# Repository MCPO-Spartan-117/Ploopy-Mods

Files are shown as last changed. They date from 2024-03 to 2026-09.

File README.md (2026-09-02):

# Ploopy Mods

This repo is a collection of [Ploopy Mouse](https://github.com/ploopyco) Kicad Conversions, PCB Replacements and mods.  
You can visit their [store page here](https://ploopy.co) and the [firmware here](https://github.com/qmk/qmk_firmware) or their [website here](https://qmk.fm).

## Test state
Nothing has been tested, make any of this at your own risk.

## Currently has mods for:

* K = Kicad Conversions
* P = PCB Replacements
* M = Mods
* P+M = PCB Replacement only Mods
* P=M = PCB Replacement that require Mods

[Ploopy Thumb Trackball](https://github.com/ploopyco/thumb-trackball): P P=M

## Directories:

* Models: A directory for 3D models made from or for either Kicad or Freecad
* PCBs: Where kicad PCBs are stored
* Printables: Models you are meant to print
* Project-files: Global directory for Kicad symbols and footprints

## TODO:

* Rotary Encoder version + Lighter scroll wheel
* Rework optical sensor version
* (Full?) hall effect sensor version
* D2FC switches version?
* Ribbion cable/cabled version?
* Seperated/PCBless design
* Remake BTUs
* 3-4mm BTUs?
* PTFE BTUs?
* Port to other Ploopies
* Port to other PCB Manufacturers
* (Handsolderable?) LEDs?
* Port originals to kicad?
* Convert originals to ARM?

## Contributions

You want to help checking off the todo list, make mods of your own and submit them or think you can make a existing mod better?  
You can make a [pull request](https://docs.github.com/en/pull-requests/collaborating-with-pull-requests/proposing-changes-to-your-work-with-pull-requests/creating-a-pull-request) detailing what you are doing and we'll look over it.

However please use [Kicad for PCBs](https://www.kicad.org) or [Freecad for Models](https://www.freecad.org) and use their native formats, they are open source, free and easily obtainable, using other CADs and/or formats will make it harder to work with and we may outright reject them because of this.

This resource is good for [learning markdown](https://www.markdownguide.org/basic-syntax) for any READMEs.

## Kicad Instructions

1. Use the [Archive 3D Models Plugin](https://github.com/MitjaNemec/Archive3DModels) for Kicad with the default path.
2. Make relative symlinks named Project-files and packages3D to Project-files and Models/Kicad respectively in your PCB project directory, it will keep all the symbols, footprint and 3D models in one place to make it easily transportable, example in PCBs/JLCPCB/Thumb-v1.

## Freecad Instructions

1. Nothing atm.

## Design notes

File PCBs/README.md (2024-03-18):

Put your PCB directory under a subdirectory named after the PCB Manufacturer here or in the Prototype directory if you haven't made it for any specific manufacturer.  
(no guarantee they'll be accepted by the manufactor you choose if they don't conform to their specs).

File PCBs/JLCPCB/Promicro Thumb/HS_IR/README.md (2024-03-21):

# Promicro Thumb-HS_IR
## WARNING, THIS BOARD IS MEANT FOR A 3.3V BOARD, THE SENSOR WON'T WORK AS IT ONLY HAS A REGULATOR FOR 3.3V to 1.8V FOR THE LED, NOT THE SENSOR'S 3.3V!!!

This PCB is designed to offload all the processing to a 3.3V Promicro sized/pinout board, so we can work with a 2 layer board and we can replace the processing board with a better/more functioning one if we want to.  
We intentionally didn't use the USB VBUS directly for components as we wanted to be able to support wireless [ZMK](https://zmk.dev) boards when it gets support for mouse APIs and we have a place where you can install a battery and switch.

These boards don't use a ESD component as it's on the MCU board.

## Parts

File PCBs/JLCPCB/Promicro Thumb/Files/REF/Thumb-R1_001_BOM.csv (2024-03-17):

Comment | Description | Designator | Quantity | Man. Part Number
D2LS-21 | Compact Surface-mounting Switch for long durability | BTN.SW.3, BTN.SW.4, BTN.SW.6, BTN.SW.8, LBS.SW.1, LBS.SW.2 | 6
0805 | 0805, X5R or better, Chip resistor, 1/8W 100PPM, Chip resistor | LED.C.20, LED.C.23, LED.R.9, LED.R.16, MCU.C.1, MCU.C.4, MCU.C.5, MCU.C.6, MCU.C.7, MCU.C.8, MCU.C.9, MCU.C.22, MCU.R.1, MCU.R.8, MOS.C.10, MOS.C.11, MOS.R.3, MOS.R.4, MOS.R.5, REG.C.12, REG.C.13, REG.C.14, REG.C.15, REG.C.16, REG.C.17, REG.C.18, SCW.R.1, SCW.R.2, SCW.R.3, SCW.R.4, USB.R.6, USB.R.7, USB.R.12, USB.R.13, USB.R.14, USB.R.15 | 36
IN-PI55TATPRPGPB | ADDRESS LED DISCRETE SERIAL RGB | LED.D.1, LED.D.3 | 2
IPC-7351 Fiducial 1mm | IPC-7351 Fiducial 1mm | MCH.FID.1, MCH.FID.2 | 2
Atmel_ICSP | 6-pin 0.100" ICSP header | MCU.J.1 | 1
HEADER2 | 2-pin 0.100" header | MCU.J.2 | 1
ATMEGA32U4RC-AU | IC MCU 8BIT 32KB FLASH 44TQFP | MCU.U.1 | 1
LFXTAL055663BULK | 8MHz ±20ppm Crystal 18pF 150 Ohms 4-SMD, No Lead | MCU.Y.1 | 1
PMW3360DM-T2QU | Optical Gaming Navigation Sensor | MOS.U.2 | 1
AP2202K-3.3 | 3.3V 150mA LDO regulator | REG.U.3 | 1
AP2204K-1.8 | Linear Voltage Regulator IC 1 Output 150mA SOT-23-5 | REG.U.4 | 1
IR12-21C/TR8 or VSMB10940 | Infrared (IR) Emitter 880nm 1.3V 50mA 1mW/sr @ 20mA 30° 2-SMD, No Lead | SCW.D.11, SCW.D.12 | 2
PT26-51B/TR8 or PT12-21B/TR8 | Phototransistor 940nm Side View 1206 (3216 Metric) | SCW.Qt.1, SCW.Qt.2 | 2
ACML-0805-601-T | FERRITE BEAD 600 OHM 0805 1LN | USB.FB.1, USB.FB.2, USB.FB.3 | 3
DX07S016JA1R1500 | USB-C (USB TYPE-C) USB 2.0 Receptacle Connector 24 (16+8 Dummy) Position Surface Mount, Right Angle; Through Hole | USB.J.3 | 1
IP4220CZ6,125 | TVS DIODE 5.5V 6TSOP (Low capacitance, USB) | USB.Z.1 | 1

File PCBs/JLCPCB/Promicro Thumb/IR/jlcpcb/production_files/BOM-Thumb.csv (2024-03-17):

Comment | Designator | Footprint | LCSC
600 | FB1,FB2,FB3 | R_0805_2012Metric | C1017
2u2 | C1,C2,C3,C4 | C_0805_2012Metric | C15850
100R | R5,R7 | R_0805_2012Metric | C17408
10k | R3 | R_0805_2012Metric | C17414
1k | R6,R8 | R_0805_2012Metric | C17513
39R | R4 | R_0805_2012Metric | C17634
5k1 | R1,R2 | R_0805_2012Metric | C27834
XC6206P182MR | U2 | SOT-23-3 | C2909966
USB_C_Receptacle_USB2.0 | J1 | USB_C_Receptacle_G-Switch_GT-USB-7010ASV | C2988369
IR12-21C/TR8 | D1,D2 | IR12-21C_TR8 | C53672
PT26-51B/TR8 | Q1,Q2 | PT26-51B_TR8 | C55976

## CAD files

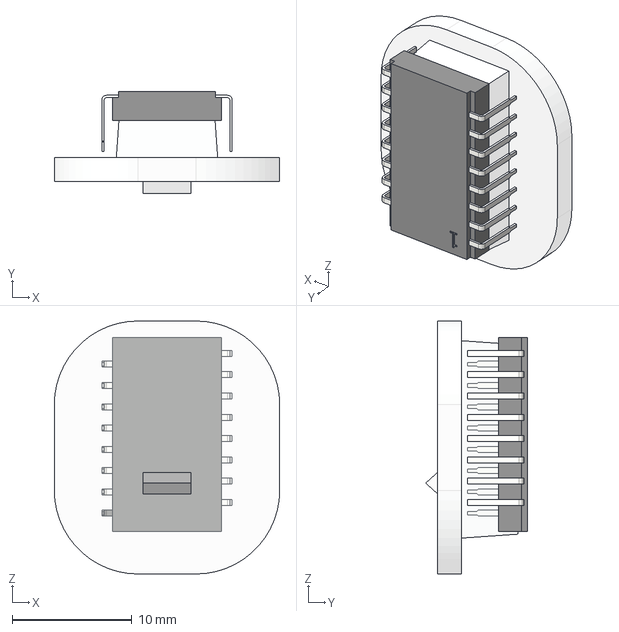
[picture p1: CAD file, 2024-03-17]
Models/Kicad/PMW3360-LM19-LSI-Assembly.stp
18.8 x 8.50 x 21.1 mm
LM19-LSI
PMW3360DM-T2QU

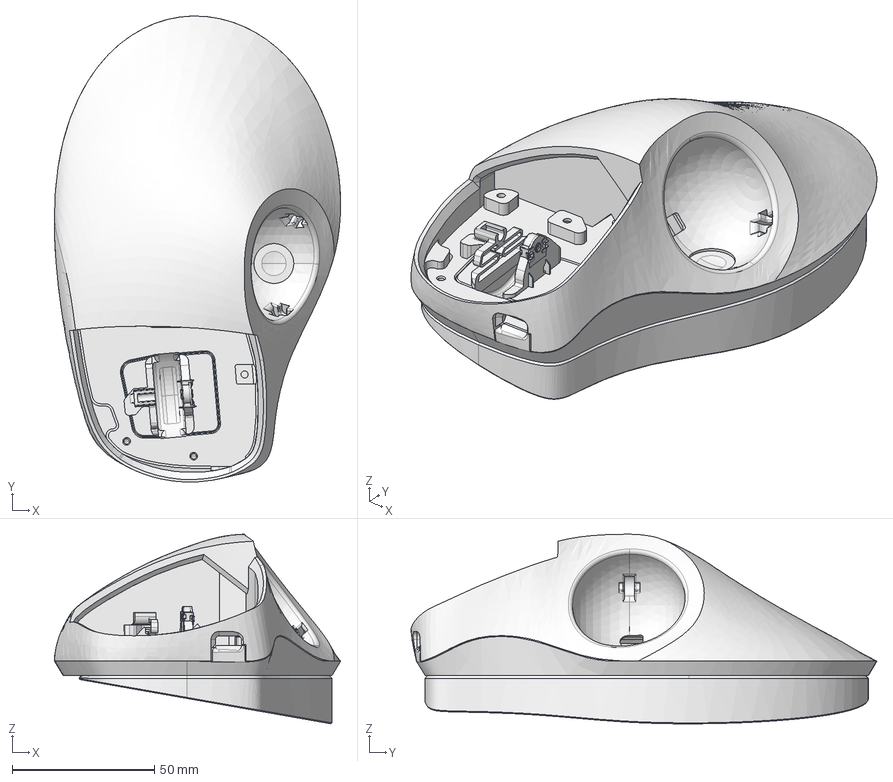
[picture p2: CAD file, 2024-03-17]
Models/Freecad/sensor.FCStd
100.7 x 164.0 x 66.8 mm
ThumbBodyParts-NoLogo-002
ThumbBodyParts-NoLogo-003
ThumbBodyParts-NoLogo-004
ThumbBodyParts-NoLogo-005
ThumbBodyParts-NoLogo-006

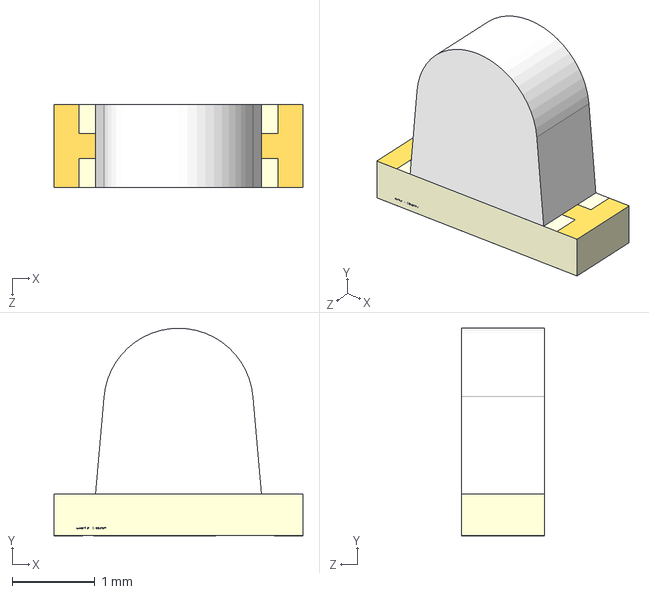
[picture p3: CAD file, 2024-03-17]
Models/Kicad/XZxx56x-1.step
3.00 x 2.50 x 1.00 mm

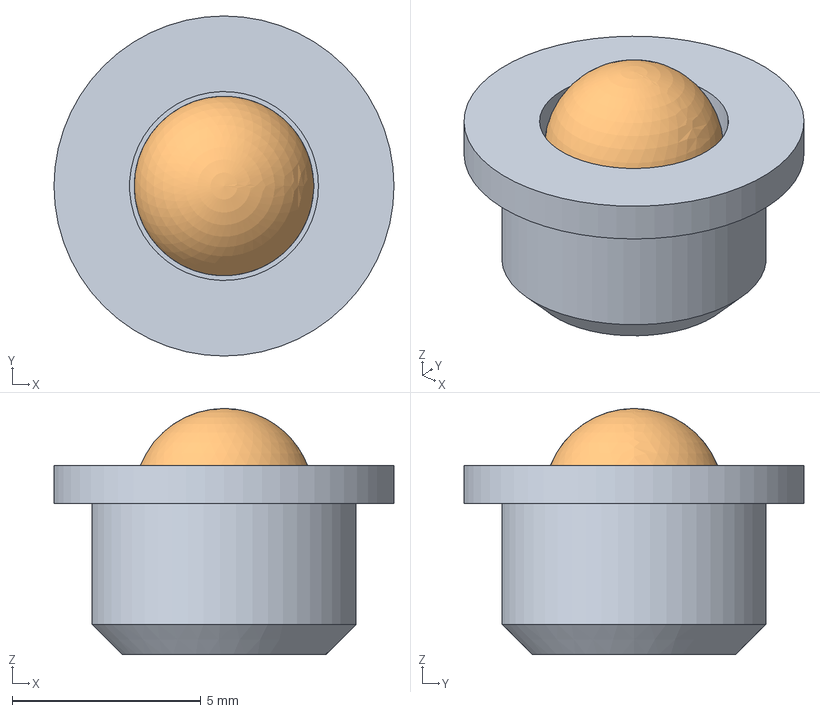
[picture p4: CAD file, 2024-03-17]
Printables/BTU-v1/BTU-7mm.FCStd
9.00 x 9.00 x 6.51 mm

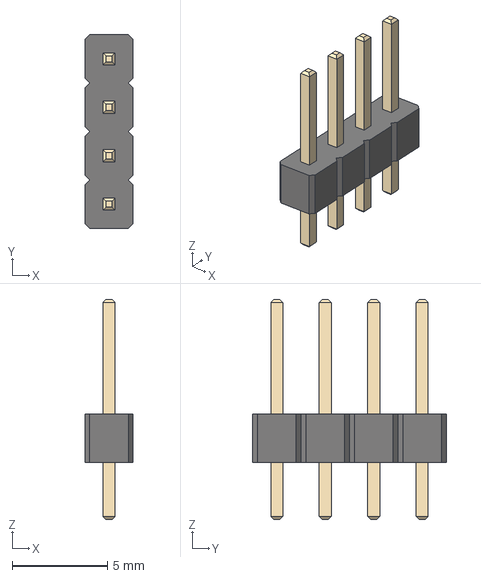
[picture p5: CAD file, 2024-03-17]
Models/Kicad/PinHeader_1x04_P2.54mm_Vertical.step
2.54 x 10.2 x 11.5 mm

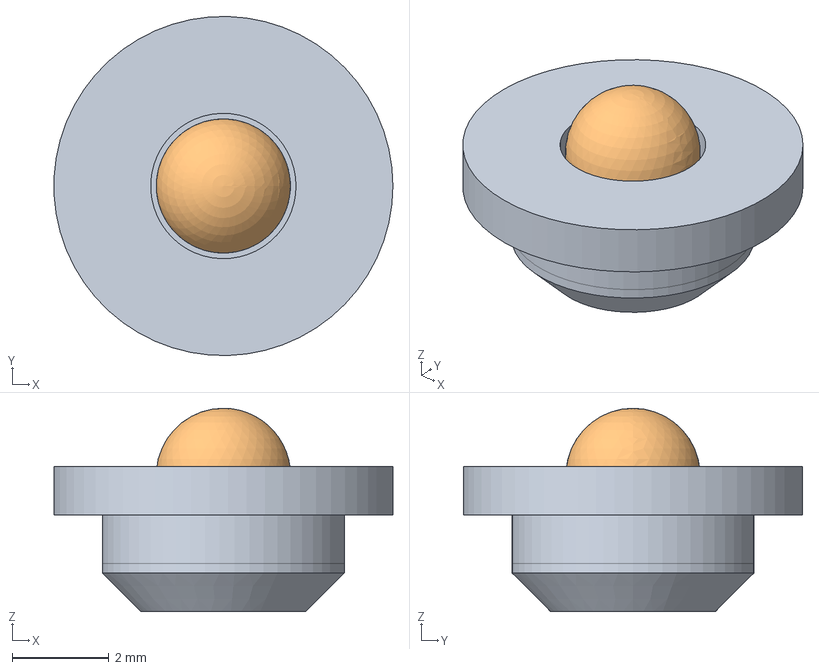
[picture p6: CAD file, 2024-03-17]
Printables/BTU-v1/BTU-5mm.FCStd
6.99 x 7.00 x 4.20 mm

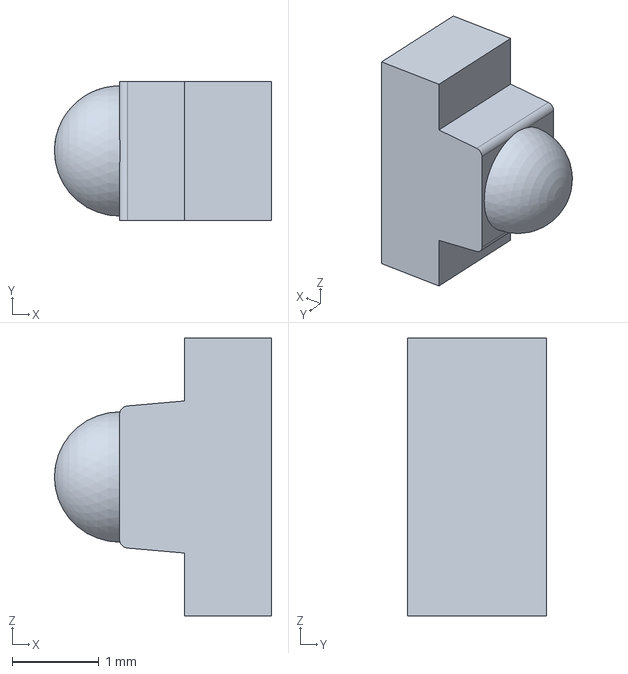
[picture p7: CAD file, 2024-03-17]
Models/Kicad/PT26-51B-TR8.stp
2.50 x 1.60 x 3.20 mm

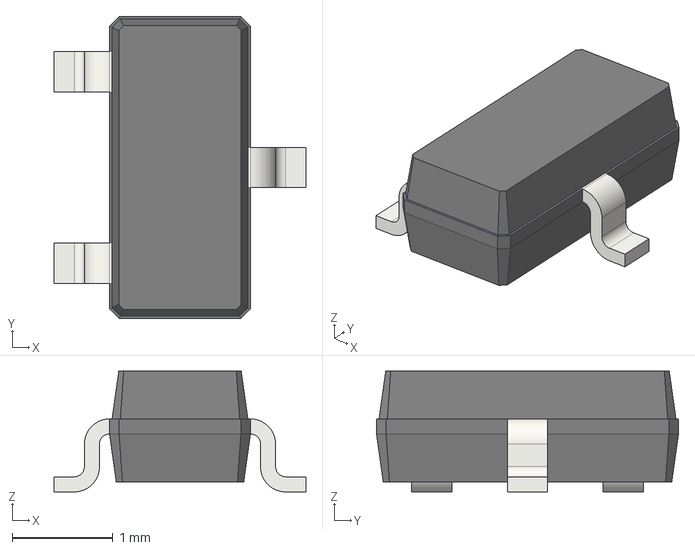
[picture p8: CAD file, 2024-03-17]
Models/Kicad/SOT-23.step
2.50 x 3.00 x 1.20 mm

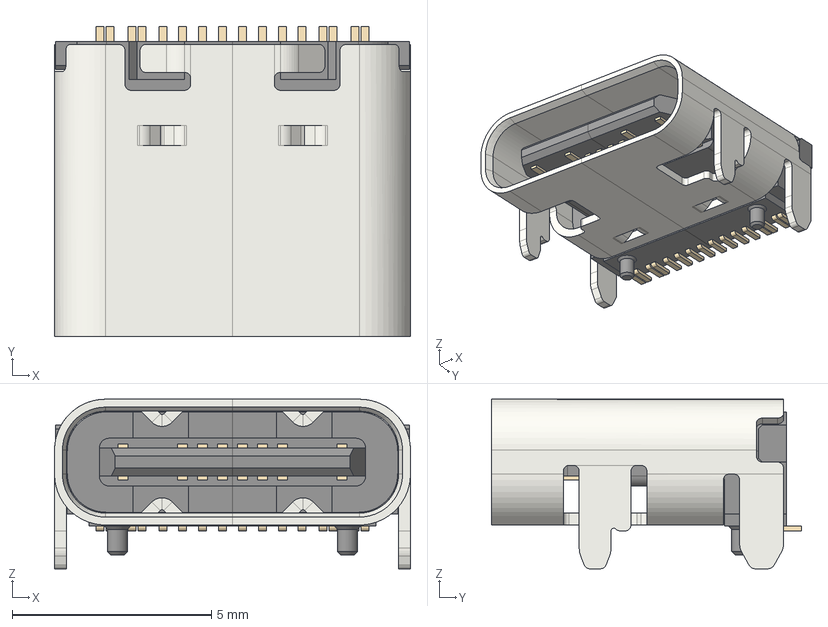
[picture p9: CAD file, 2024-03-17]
Models/Kicad/USB_C_Receptacle_GCT_USB4105-xx-A_16P_TopMnt_Horizontal.step
8.94 x 7.78 x 4.26 mm

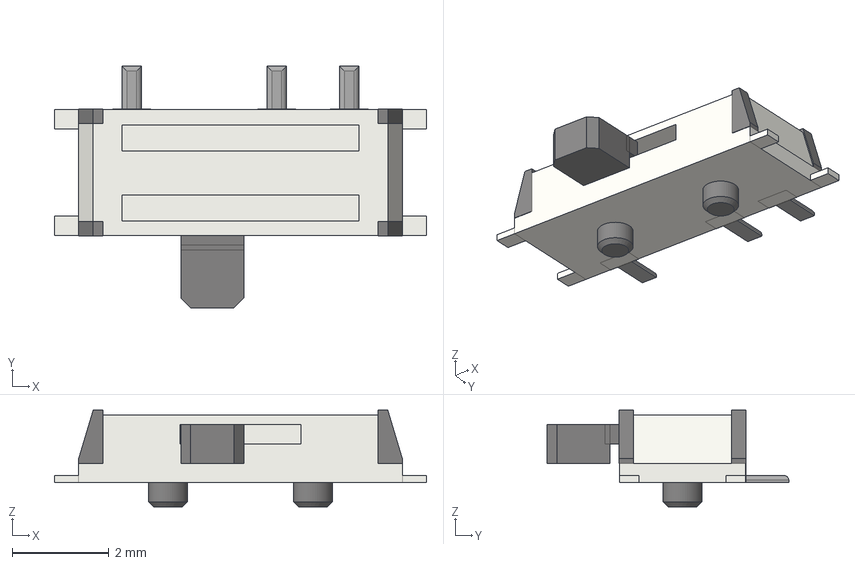
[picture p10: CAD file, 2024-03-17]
Models/Kicad/SW_SPDT_PCM12.step
7.70 x 5.00 x 2.00 mm

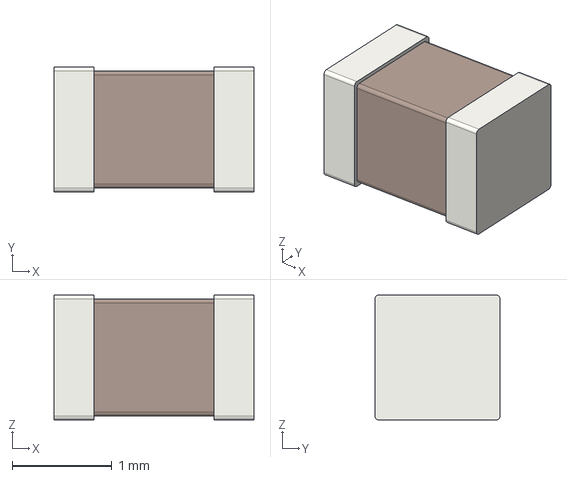
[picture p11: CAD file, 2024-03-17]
Models/Kicad/C_0805_2012Metric.step
2.00 x 1.25 x 1.25 mm

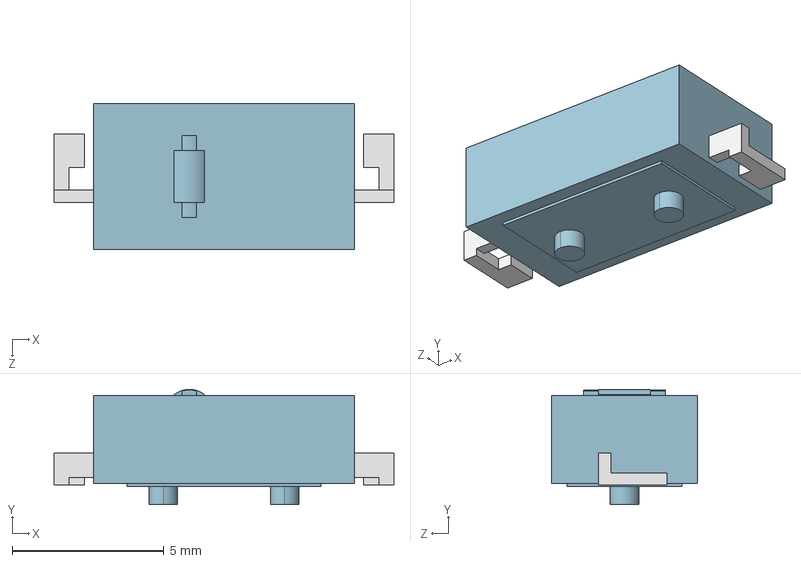
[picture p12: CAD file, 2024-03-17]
Models/Kicad/D2LS_21_20M.step
11.2 x 3.80 x 4.80 mm
D2LS_21_20M_BUTTON
D2LS_21_20M_BASE

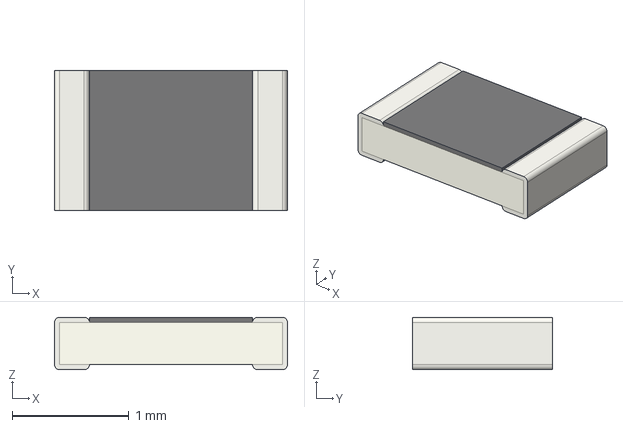
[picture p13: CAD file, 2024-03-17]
Models/Kicad/R_0805_2012Metric.step
2.00 x 1.20 x 0.45 mm

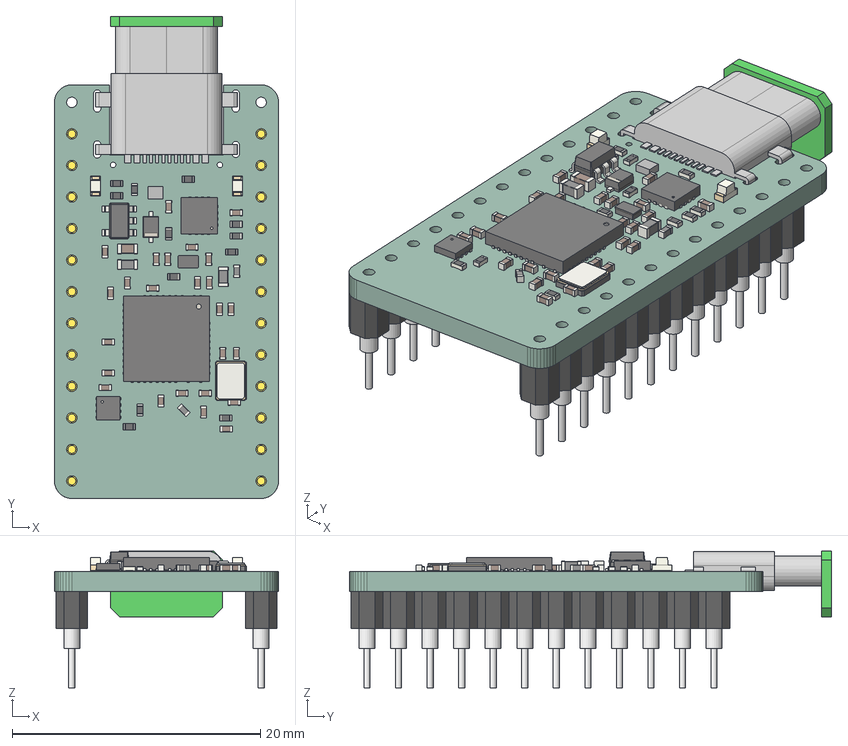
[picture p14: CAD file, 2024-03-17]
Models/Kicad/promicro.step
18.0 x 38.8 x 11.0 mm
mikoto PCB

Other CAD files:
Models/Kicad/PR(E,P)C003DAAN-RC.stp
Models/Kicad/m20-9990245_asm.stp

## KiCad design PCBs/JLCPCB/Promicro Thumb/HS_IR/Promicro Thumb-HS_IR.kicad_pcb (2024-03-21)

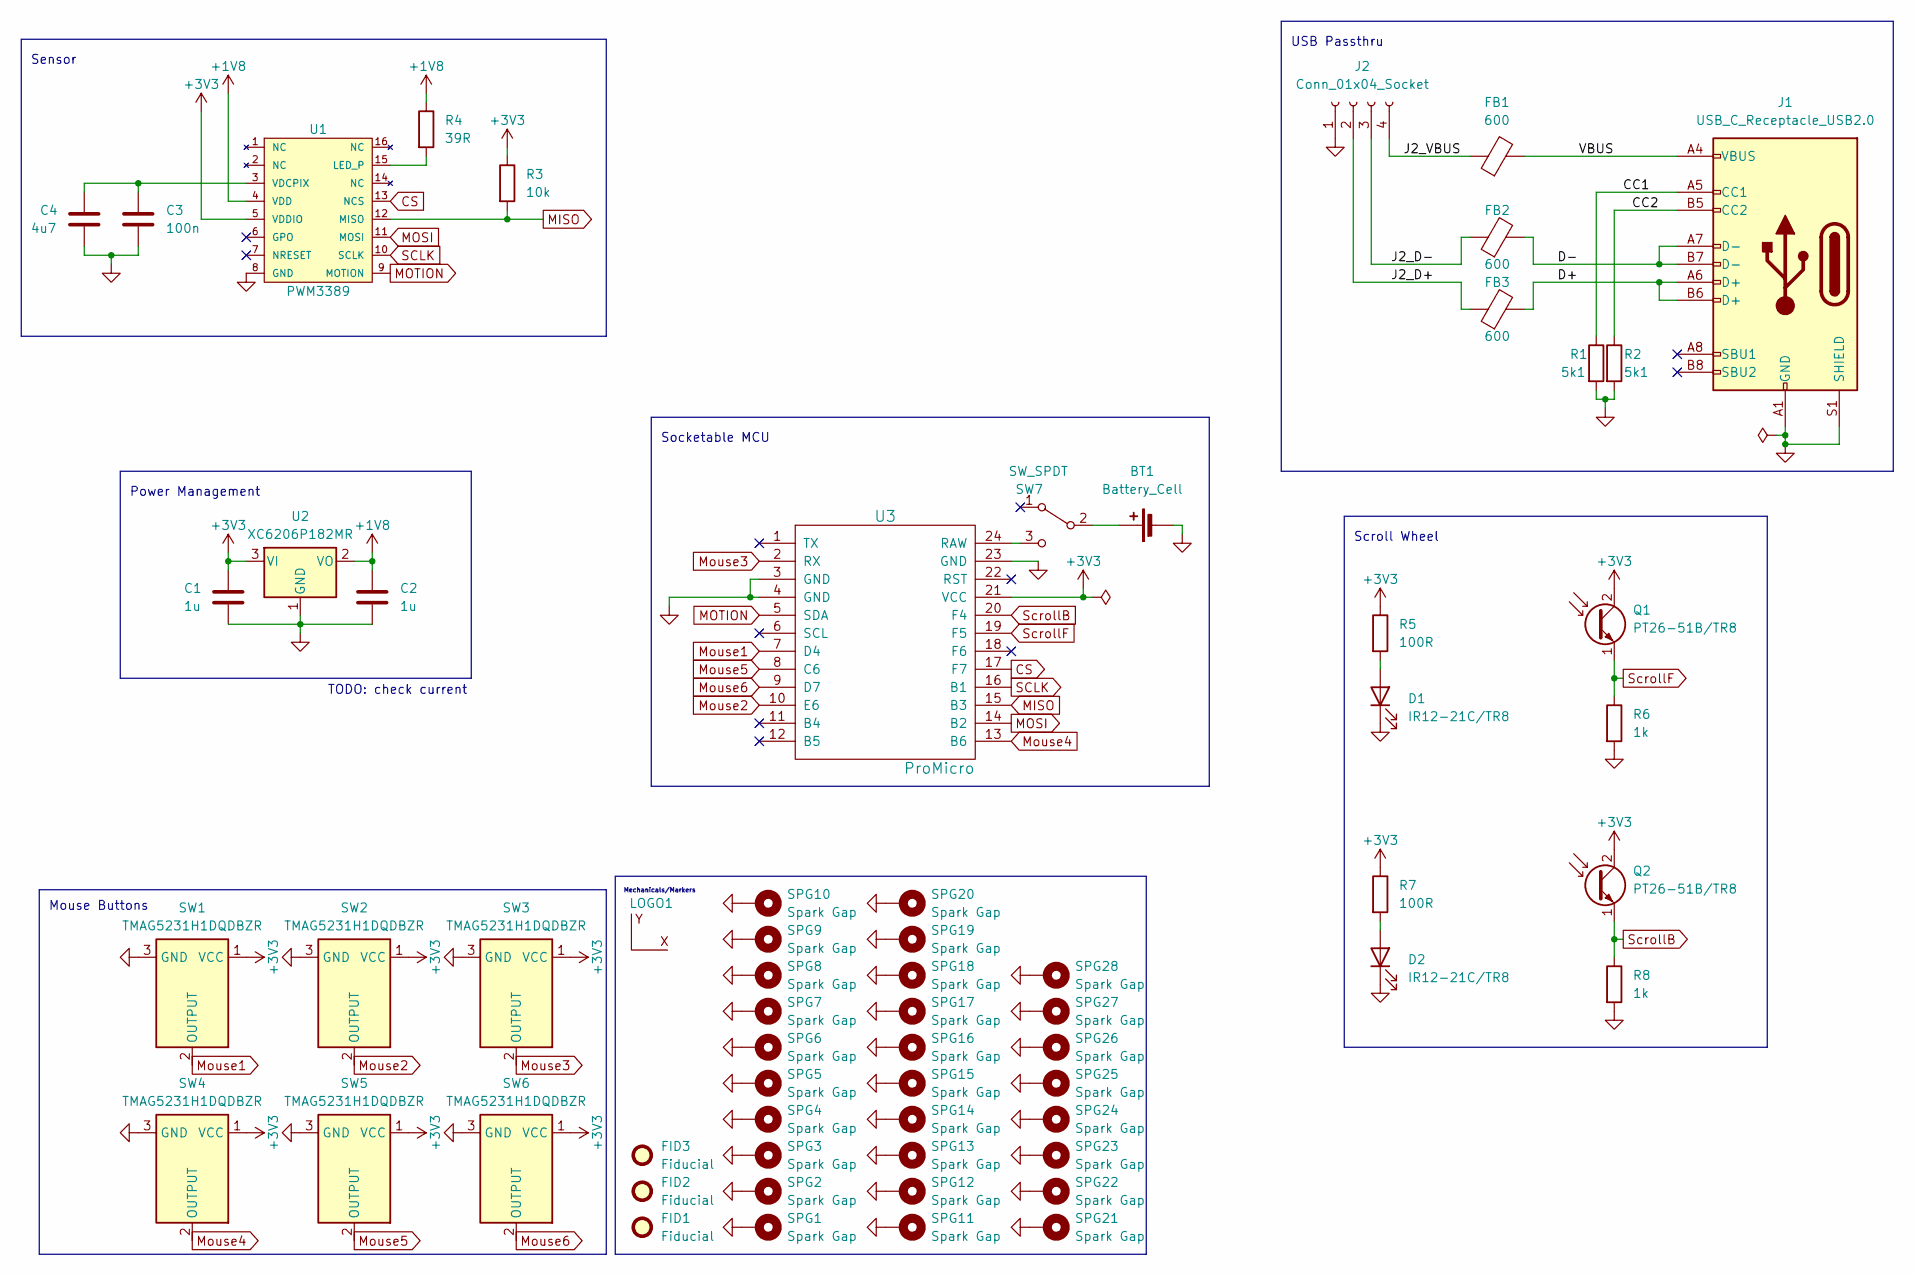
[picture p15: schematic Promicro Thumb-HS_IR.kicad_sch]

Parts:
BT1: Battery_Cell; Battery_pads_reversible
C1, C2: 1u; C_0805_2012Metric
C3: 100n; C_0805_2012Metric
C4: 4u7; C_0805_2012Metric
D1, D2: IR12-21C/TR8; IR12-21C_TR8
FB1, FB2, FB3: 600; R_0805_2012Metric
FID1, FID2, FID3: Fiducial; Fiducial_0.5mm_Mask1mm
J1: USB_C_Receptacle_USB2.0; USB_C_Receptacle_G-Switch_GT-USB-7010ASV
J2: Conn_01x04_Socket; PinHeader_1x04_P2.54mm_Vertical
LOGO1: Coordinate System-Ploopy
Q1, Q2: PT26-51B/TR8; PT26-51B_TR8
R1, R2: 5k1; R_0805_2012Metric
R3: 10k; R_0805_2012Metric
R4: 39R; R_0805_2012Metric
R5, R7: 100R; R_0805_2012Metric
R6, R8: 1k; R_0805_2012Metric
SPG1, SPG2, SPG3, SPG4, SPG5, SPG6, SPG7, SPG8, SPG9, SPG10, SPG11, SPG12, SPG13, SPG14, SPG15, SPG16, SPG17, SPG18, SPG19, SPG20, SPG21, SPG22, SPG23, SPG24, SPG25, SPG26, SPG27, SPG28: Spark Gap; SparkGap
SW1, SW2, SW3, SW4, SW5, SW6: TMAG5231H1DQDBZR; SOT-23
SW7: SW_SPDT; SW_SPDT_PCM12
U1: PWM3389; PMW3360DM-T2QU
U2: XC6206P182MR; SOT-23-3
U3: ProMicro

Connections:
+1V8: C2.1, R4.1, U1.4 (VDD), U2.2 (VO)
+3V3: C1.1, Q1.2 (C), Q2.2 (C), R3.1, R5.1, R7.1, SW1.1 (VCC), SW2.1 (VCC), SW3.1 (VCC), SW4.1 (VCC), SW5.1 (VCC), SW6.1 (VCC), U1.5 (VDDIO), U2.3 (VI), U3.21 (VCC)
/CC1: J1.A5 (CC1), R1.1
/CC2: J1.B5 (CC2), R2.1
/D+: FB3.2, J1.A6 (D+), J1.B6 (D+)
/D-: FB2.2, J1.A7 (D-), J1.B7 (D-)
/J2_D+: FB3.1, J2.2
/J2_D-: FB2.1, J2.3
/J2_VBUS: FB1.1, J2.4
/VBUS: FB1.2, J1.A4 (VBUS), J1.A9 (VBUS), J1.B4 (VBUS), J1.B9 (VBUS)
CS: U1.13 (NCS), U3.17 (F7)
GND: BT1.2 (-), C1.2, C2.2, C3.2, C4.2, D1.1 (K), D2.1 (K), J1.A1 (GND), J1.A12 (GND), J1.B1 (GND), J1.B12 (GND), J1.S1 (SHIELD), J2.1, R1.2, R2.2, R6.2, R8.2, SPG1.1, SPG2.1, SPG3.1, SPG4.1, SPG5.1, SPG6.1, SPG7.1, SPG8.1, SPG9.1, SPG10.1, SPG11.1, SPG12.1, SPG13.1, SPG14.1, SPG15.1, SPG16.1, SPG17.1, SPG18.1, SPG19.1, SPG20.1, SPG21.1, SPG22.1, SPG23.1, SPG24.1, SPG25.1, SPG26.1, SPG27.1, SPG28.1, SW1.3 (GND), SW2.3 (GND), SW3.3 (GND), SW4.3 (GND), SW5.3 (GND), SW6.3 (GND), U1.8 (GND), U2.1 (GND), U3.3 (GND), U3.4 (GND), U3.23 (GND)
MISO: R3.2, U1.12 (MISO), U3.15 (B3)
MOSI: U1.11 (MOSI), U3.14 (B2)
MOTION: U1.9 (MOTION), U3.5 (SDA)
Mouse1: SW1.2 (OUTPUT), U3.7 (D4)
Mouse2: SW2.2 (OUTPUT), U3.10 (E6)
Mouse3: SW3.2 (OUTPUT), U3.2 (RX)
Mouse4: SW4.2 (OUTPUT), U3.13 (B6)
Mouse5: SW5.2 (OUTPUT), U3.8 (C6)
Mouse6: SW6.2 (OUTPUT), U3.9 (D7)
unnamed: BT1.1 (+), SW7.2 (B)
unnamed: D1.2 (A), R5.2
unnamed: D2.2 (A), R7.2
unnamed: SW7.3 (C), U3.24 (RAW)
unnamed: R4.2, U1.15 (LED_P)
unnamed: C3.1, C4.1, U1.3 (VDCPIX)
SCLK: U1.10 (SCLK), U3.16 (B1)
ScrollB: Q2.1 (E), R8.1, U3.20 (F4)
ScrollF: Q1.1 (E), R6.1, U3.19 (F5)

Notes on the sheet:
Scroll Wheel
USB Passthru
Sensor
TODO: check current
Power Management
Mouse Buttons
Mechanicals/Markers
Socketable MCU

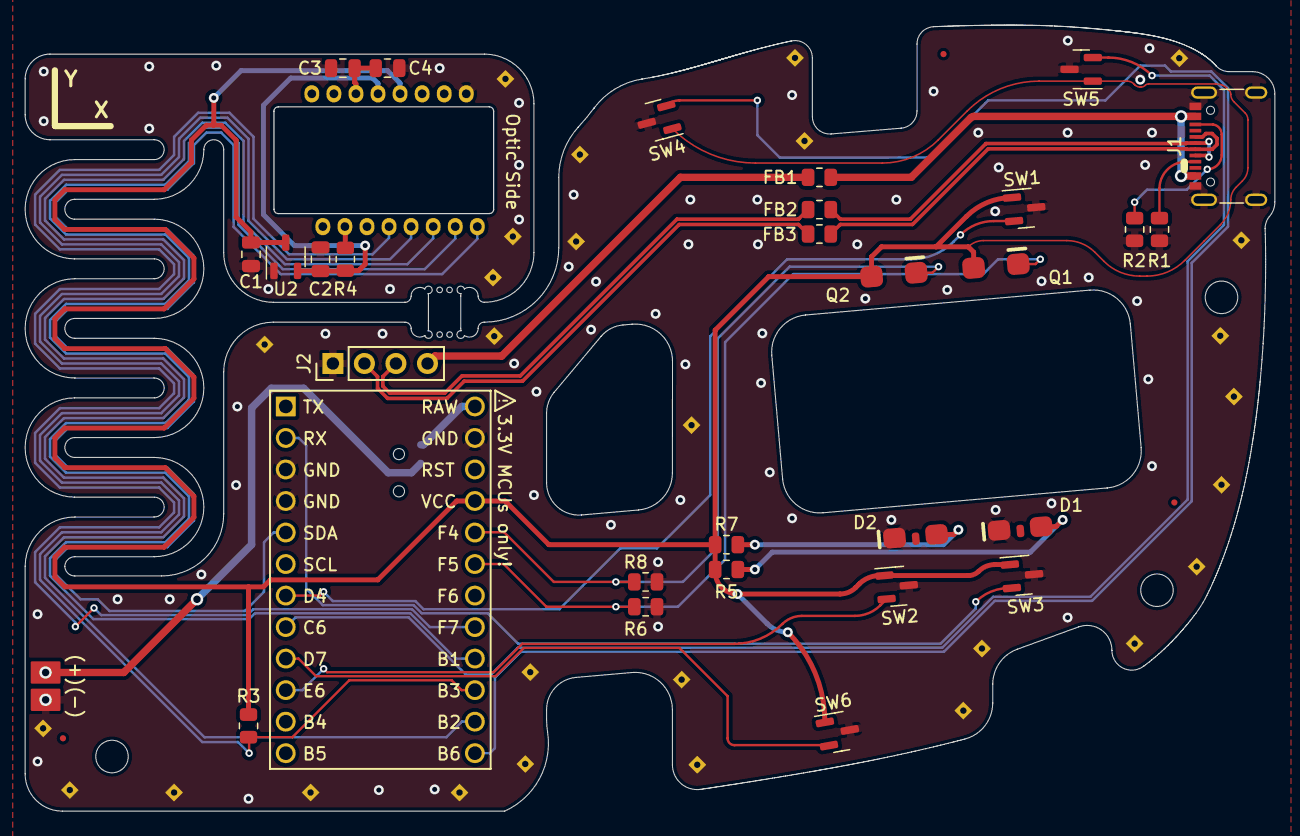
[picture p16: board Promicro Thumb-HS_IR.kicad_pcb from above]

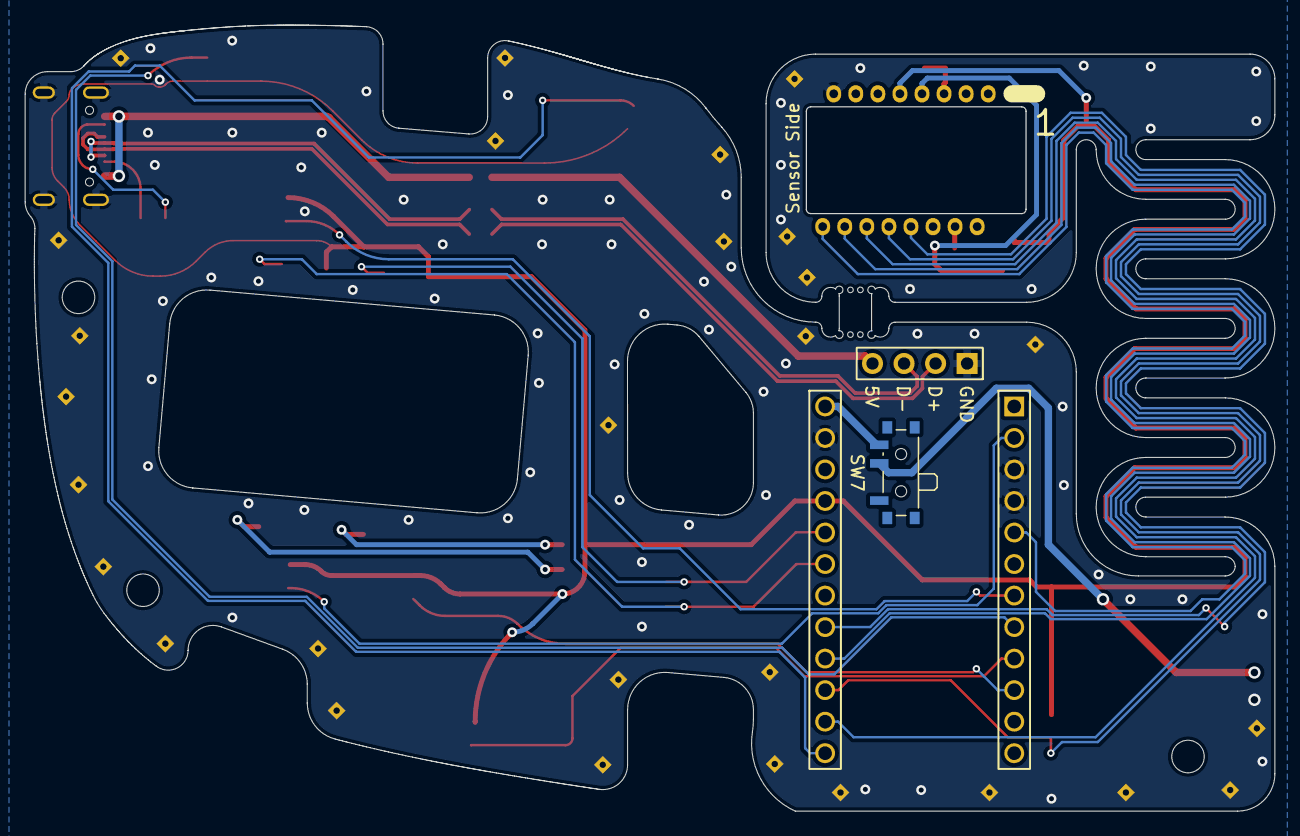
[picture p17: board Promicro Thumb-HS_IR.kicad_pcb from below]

Board: 2 copper layers, 100.7 x 63.3 mm, 64 parts (2 on the bottom side), 30 nets.

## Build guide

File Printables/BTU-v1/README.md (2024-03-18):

BTU-7mm: Basically a copy of [this listing](https://www.aliexpress.us/item/3256805177488418.html) but here are specs anyway:
* Ball: 4.763mm diameter
* Outer Ball: 1.5mm
* Subballs: 1.4mm diameter
* Gap: 4.963mm diameter
* Water Drain Hole: 1.5mm diameter
* Wall Thickness: 1mm
* Width: 7mm inner, 9mm outer
* Height: 1mm base, 4mm walls, 1mm brim

BTU-5mm: An attempt to make a smaller BTU, might be too small:
* Ball: 2.778 diameter
* Outer Ball: 1.2mm
* Subballs: 0.8mm diameter
* Gap: 2.978mm diameter
* Water Drain Hole: 1mm diameter
* Wall Thickness: 1mm
* Width: 5mm inner, 7mm outer
* Height: 1mm base, 1mm walls, 1mm brim

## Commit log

2024-03-18 Rename PCB, fix syntax and add .gitignore
    [BOM-Thumb.csv, Promicro Thumb-IR.kicad_pcb, Promicro Thumb-IR.kicad_sch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]
2024-03-20 Add Hall Sensor version, more .gitignore and updated READMEs
    [BOM-Thumb.csv, Promicro Thumb-HS_IR.kicad_pcb, Promicro Thumb-HS_IR.kicad_sch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]
2024-03-21 Smaller 3V3 tracks
    [Promicro Thumb-HS_IR.kicad_pcb]

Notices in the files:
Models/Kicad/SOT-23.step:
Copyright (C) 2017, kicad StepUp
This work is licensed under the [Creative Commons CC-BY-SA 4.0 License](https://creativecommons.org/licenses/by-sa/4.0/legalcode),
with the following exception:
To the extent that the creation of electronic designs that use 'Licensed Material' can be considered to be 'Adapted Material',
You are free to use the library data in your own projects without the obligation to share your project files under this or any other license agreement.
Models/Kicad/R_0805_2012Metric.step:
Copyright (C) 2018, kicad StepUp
